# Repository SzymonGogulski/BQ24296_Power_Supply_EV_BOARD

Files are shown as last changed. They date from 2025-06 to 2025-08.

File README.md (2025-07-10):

# BQ24296 Power Supply 5V @ 3A

### Linki
* [Simple way to use USB-C 5V@3A](https://forum.digikey.com/t/simple-way-to-use-usb-type-c-to-get-5v-at-up-to-3a-15w/7016)

### Notatki
* BQ24296
    * Sprawdź default input current limit,
    * Sprawdź czy wyjście VSYS jest regulowane na 5.0V,
    * Sprawdź co to NVDC power path management,

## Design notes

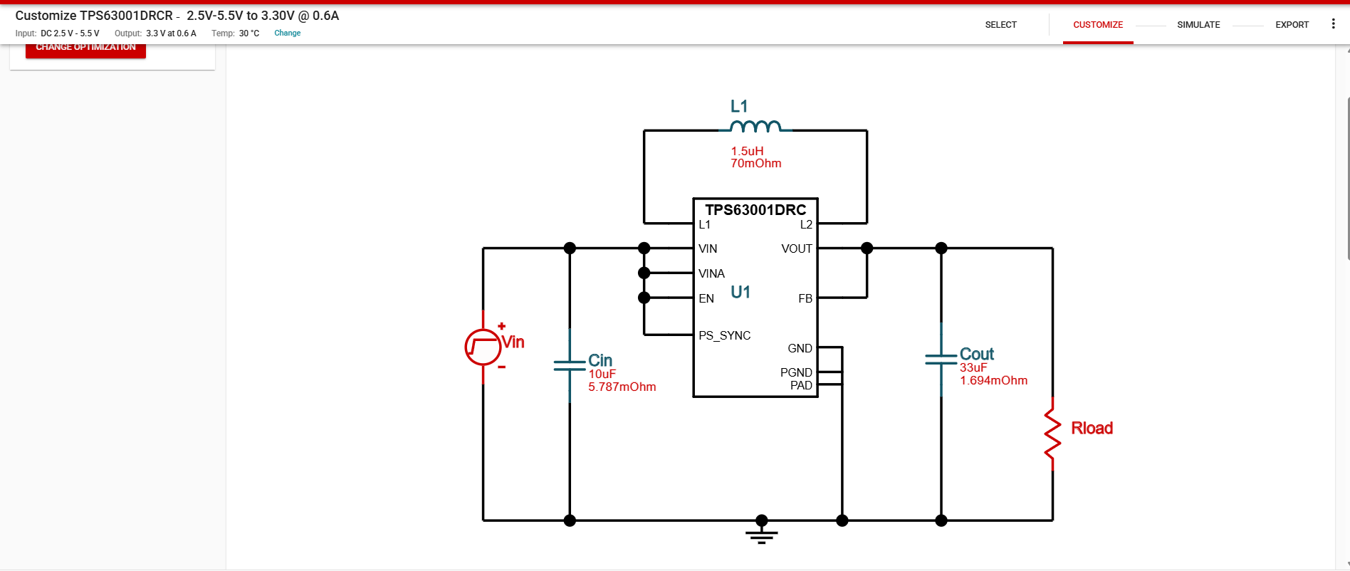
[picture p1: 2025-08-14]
Dokumentacja/3V3_24.06.2025.png

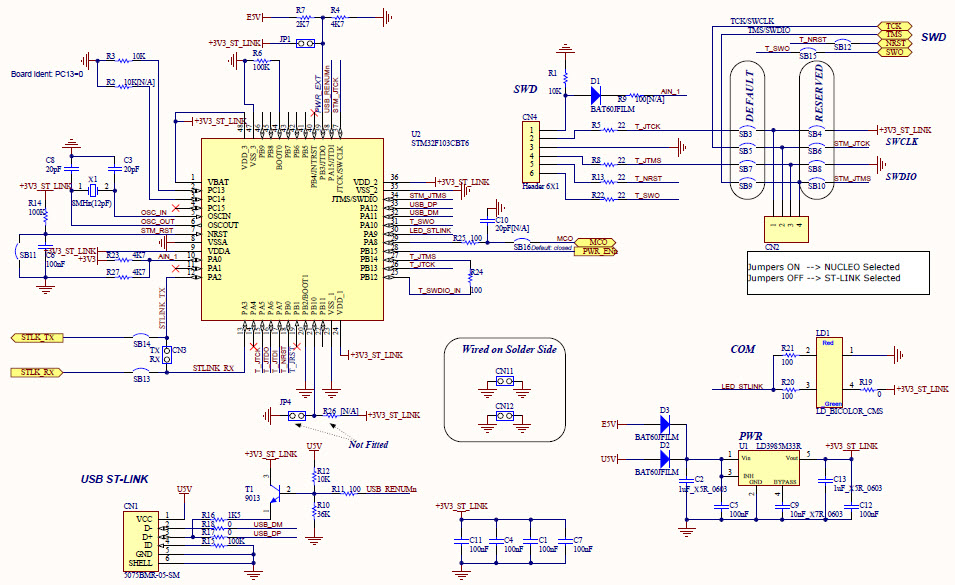
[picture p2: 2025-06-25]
Dokumentacja/stm32nucleo-64_fig.1_5.jpg

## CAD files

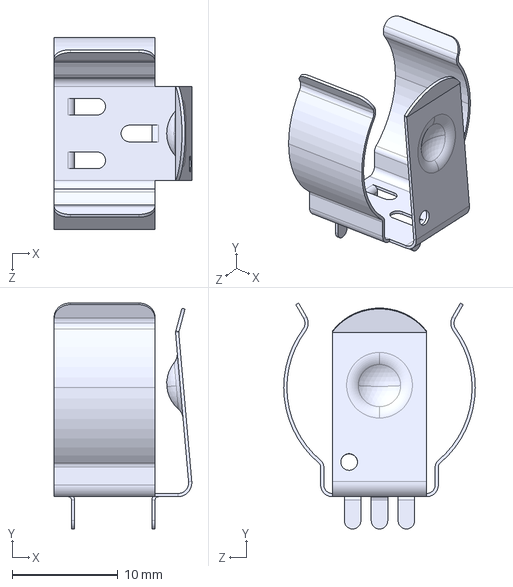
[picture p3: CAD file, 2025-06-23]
BQ2xxxx/Biblioteki/54/54.step
13.0 x 21.4 x 18.1 mm

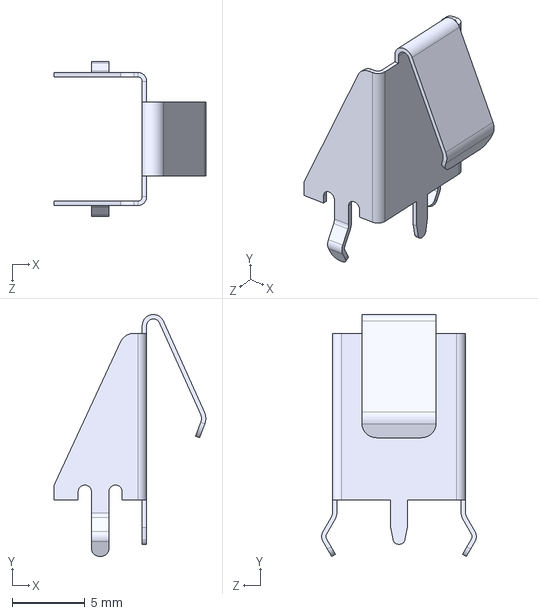
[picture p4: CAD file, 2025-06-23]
BQ2xxxx/Biblioteki/590/590.step
10.4 x 16.6 x 10.6 mm

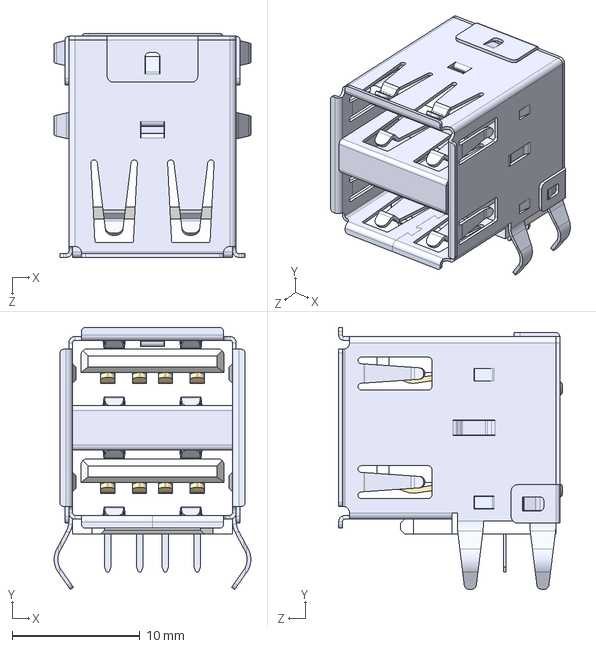
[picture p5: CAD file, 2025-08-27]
BQ2xxxx/Biblioteki/AU-Y1008-2/AU-Y1008-2.step
15.4 x 20.5 x 17.5 mm

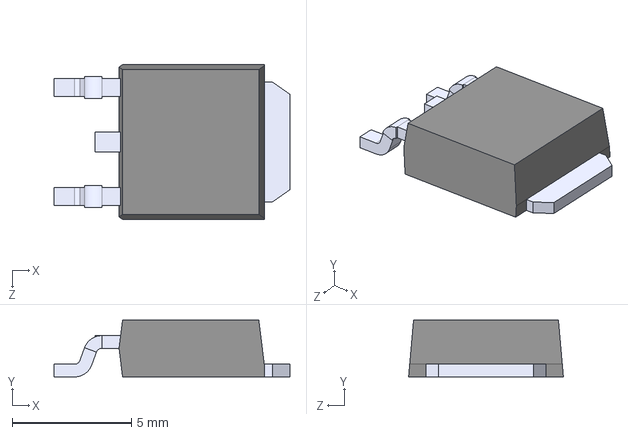
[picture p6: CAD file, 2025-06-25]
BQ2xxxx/Biblioteki/MJD31CG/MJD31CG.step
9.91 x 2.39 x 6.50 mm

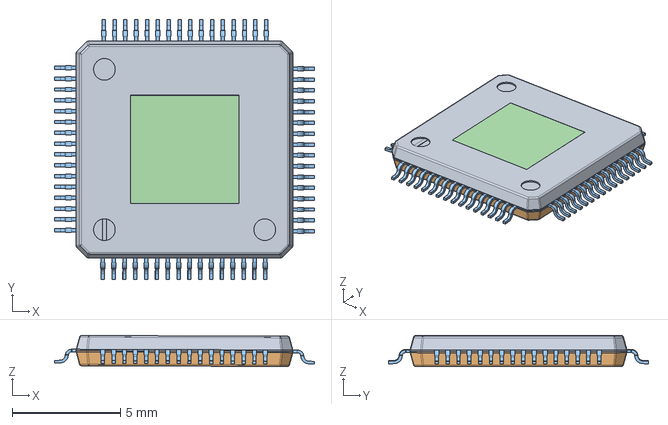
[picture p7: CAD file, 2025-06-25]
BQ2xxxx/Biblioteki/STM32F030R8T6/STM32F030R8T6.stp
12.0 x 12.0 x 1.43 mm

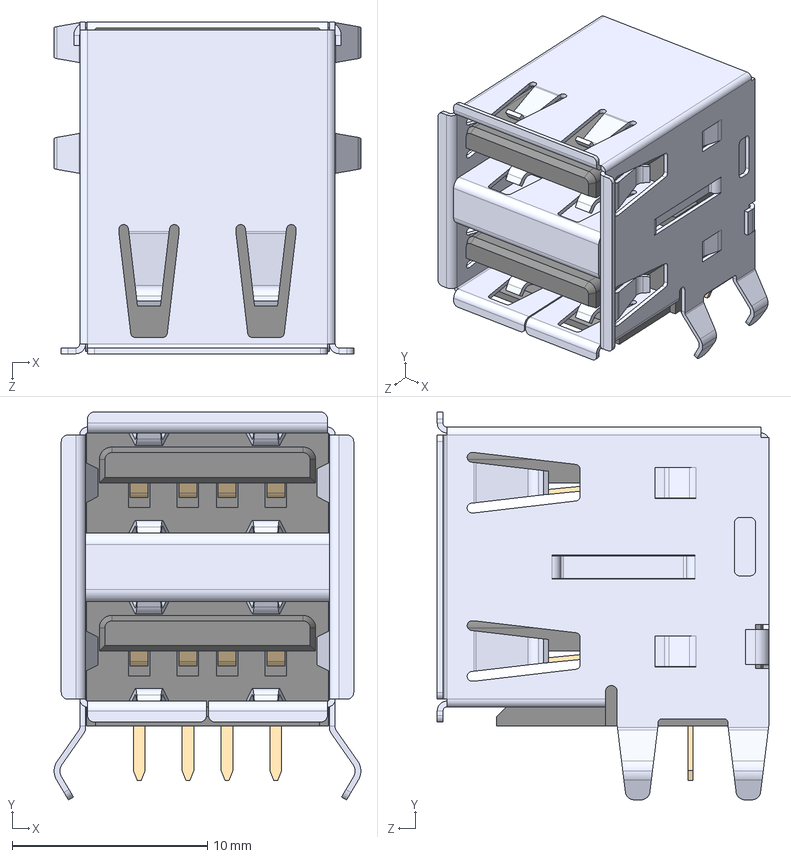
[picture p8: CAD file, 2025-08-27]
BQ2xxxx/Biblioteki/USB1035_GF_P_0_B_B/USB1035-XX-X-X-X-B_REVE.step
15.7 x 19.9 x 17.0 mm

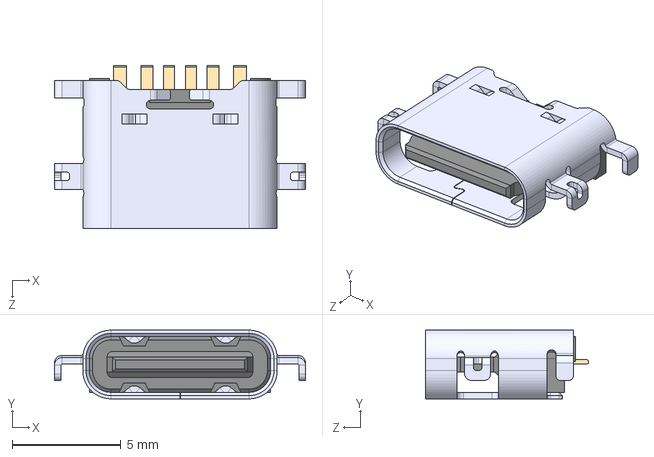
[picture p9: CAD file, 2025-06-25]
BQ2xxxx/Biblioteki/USB4515-GF-A_REVA/USB4515-GF-A_REVA.step
11.5 x 3.16 x 7.50 mm

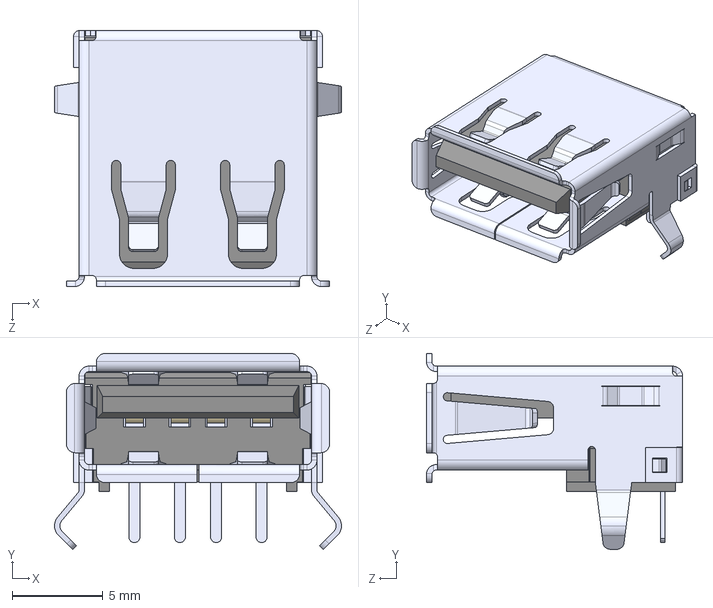
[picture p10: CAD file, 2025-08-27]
BQ2xxxx/Biblioteki/USB_A1HSW6/USB-A1HSW6.step
15.8 x 10.8 x 14.1 mm

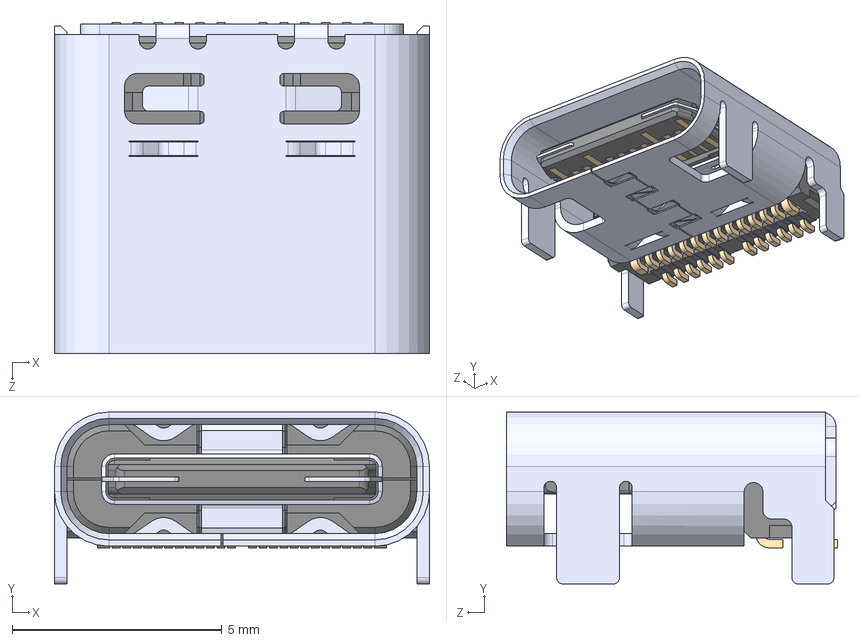
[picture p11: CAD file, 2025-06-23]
BQ2xxxx/Biblioteki/1054500101/1054500101--3DModel-STEP-1.STEP
8.94 x 4.10 x 7.90 mm

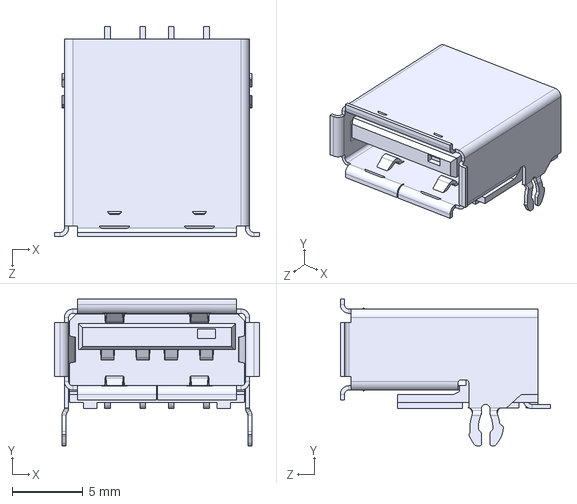
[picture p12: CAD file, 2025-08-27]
BQ2xxxx/Biblioteki/87583-0010RHLF/87583-0010RHLF.step
14.5 x 10.4 x 14.9 mm

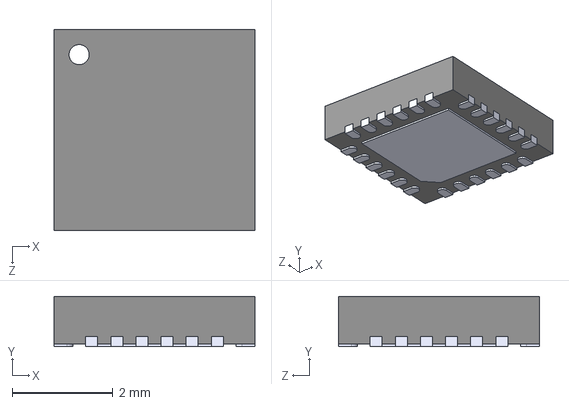
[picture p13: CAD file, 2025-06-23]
BQ2xxxx/Biblioteki/BQ24296MRGER/BQ24296MRGER.step
4.00 x 1.00 x 4.00 mm

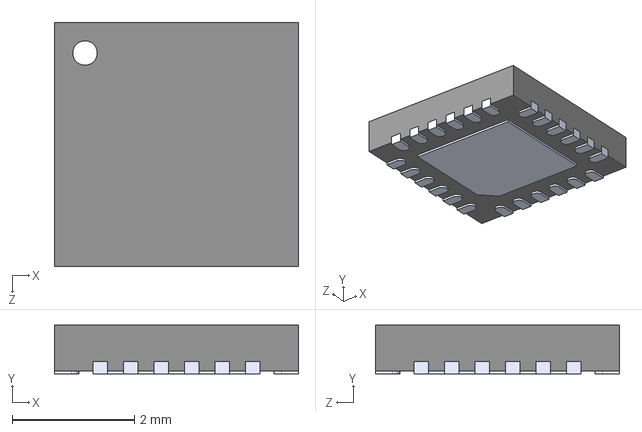
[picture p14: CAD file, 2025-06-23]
BQ2xxxx/Biblioteki/BQ25895MRTWT/BQ25895MRTWT.step
4.00 x 0.8 x 4.00 mm

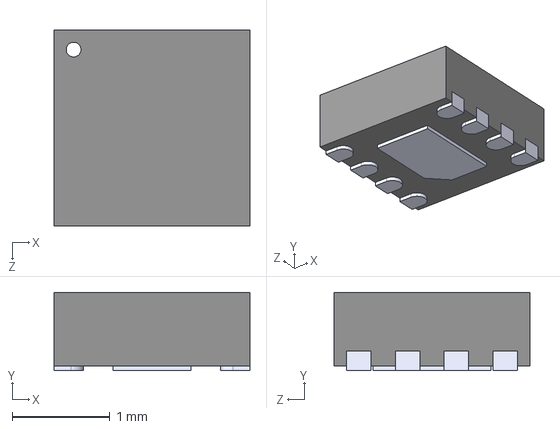
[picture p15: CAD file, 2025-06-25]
BQ2xxxx/Biblioteki/MAX17048G_T10/MAX17048G_T10.step
2.00 x 0.8 x 2.00 mm

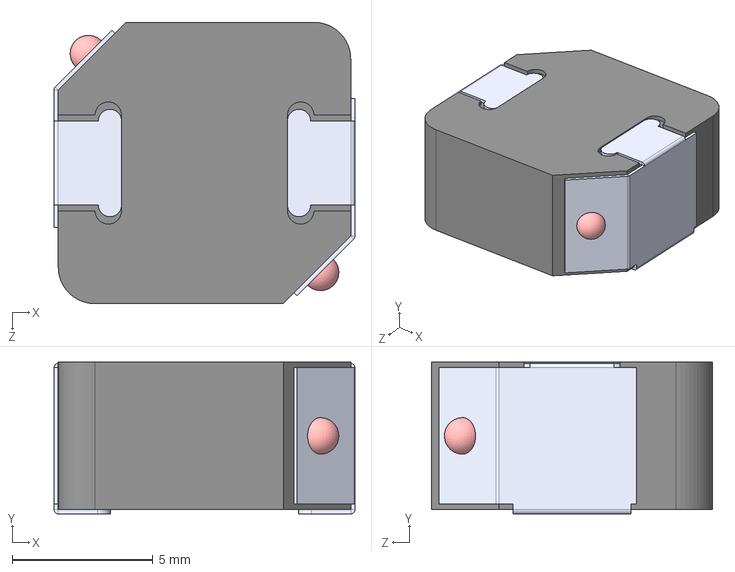
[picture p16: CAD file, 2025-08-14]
BQ2xxxx/Biblioteki/SPM10054T_1R5M_HZ/SPM10054T-1R5M-HZ.step
10.7 x 5.40 x 10.0 mm

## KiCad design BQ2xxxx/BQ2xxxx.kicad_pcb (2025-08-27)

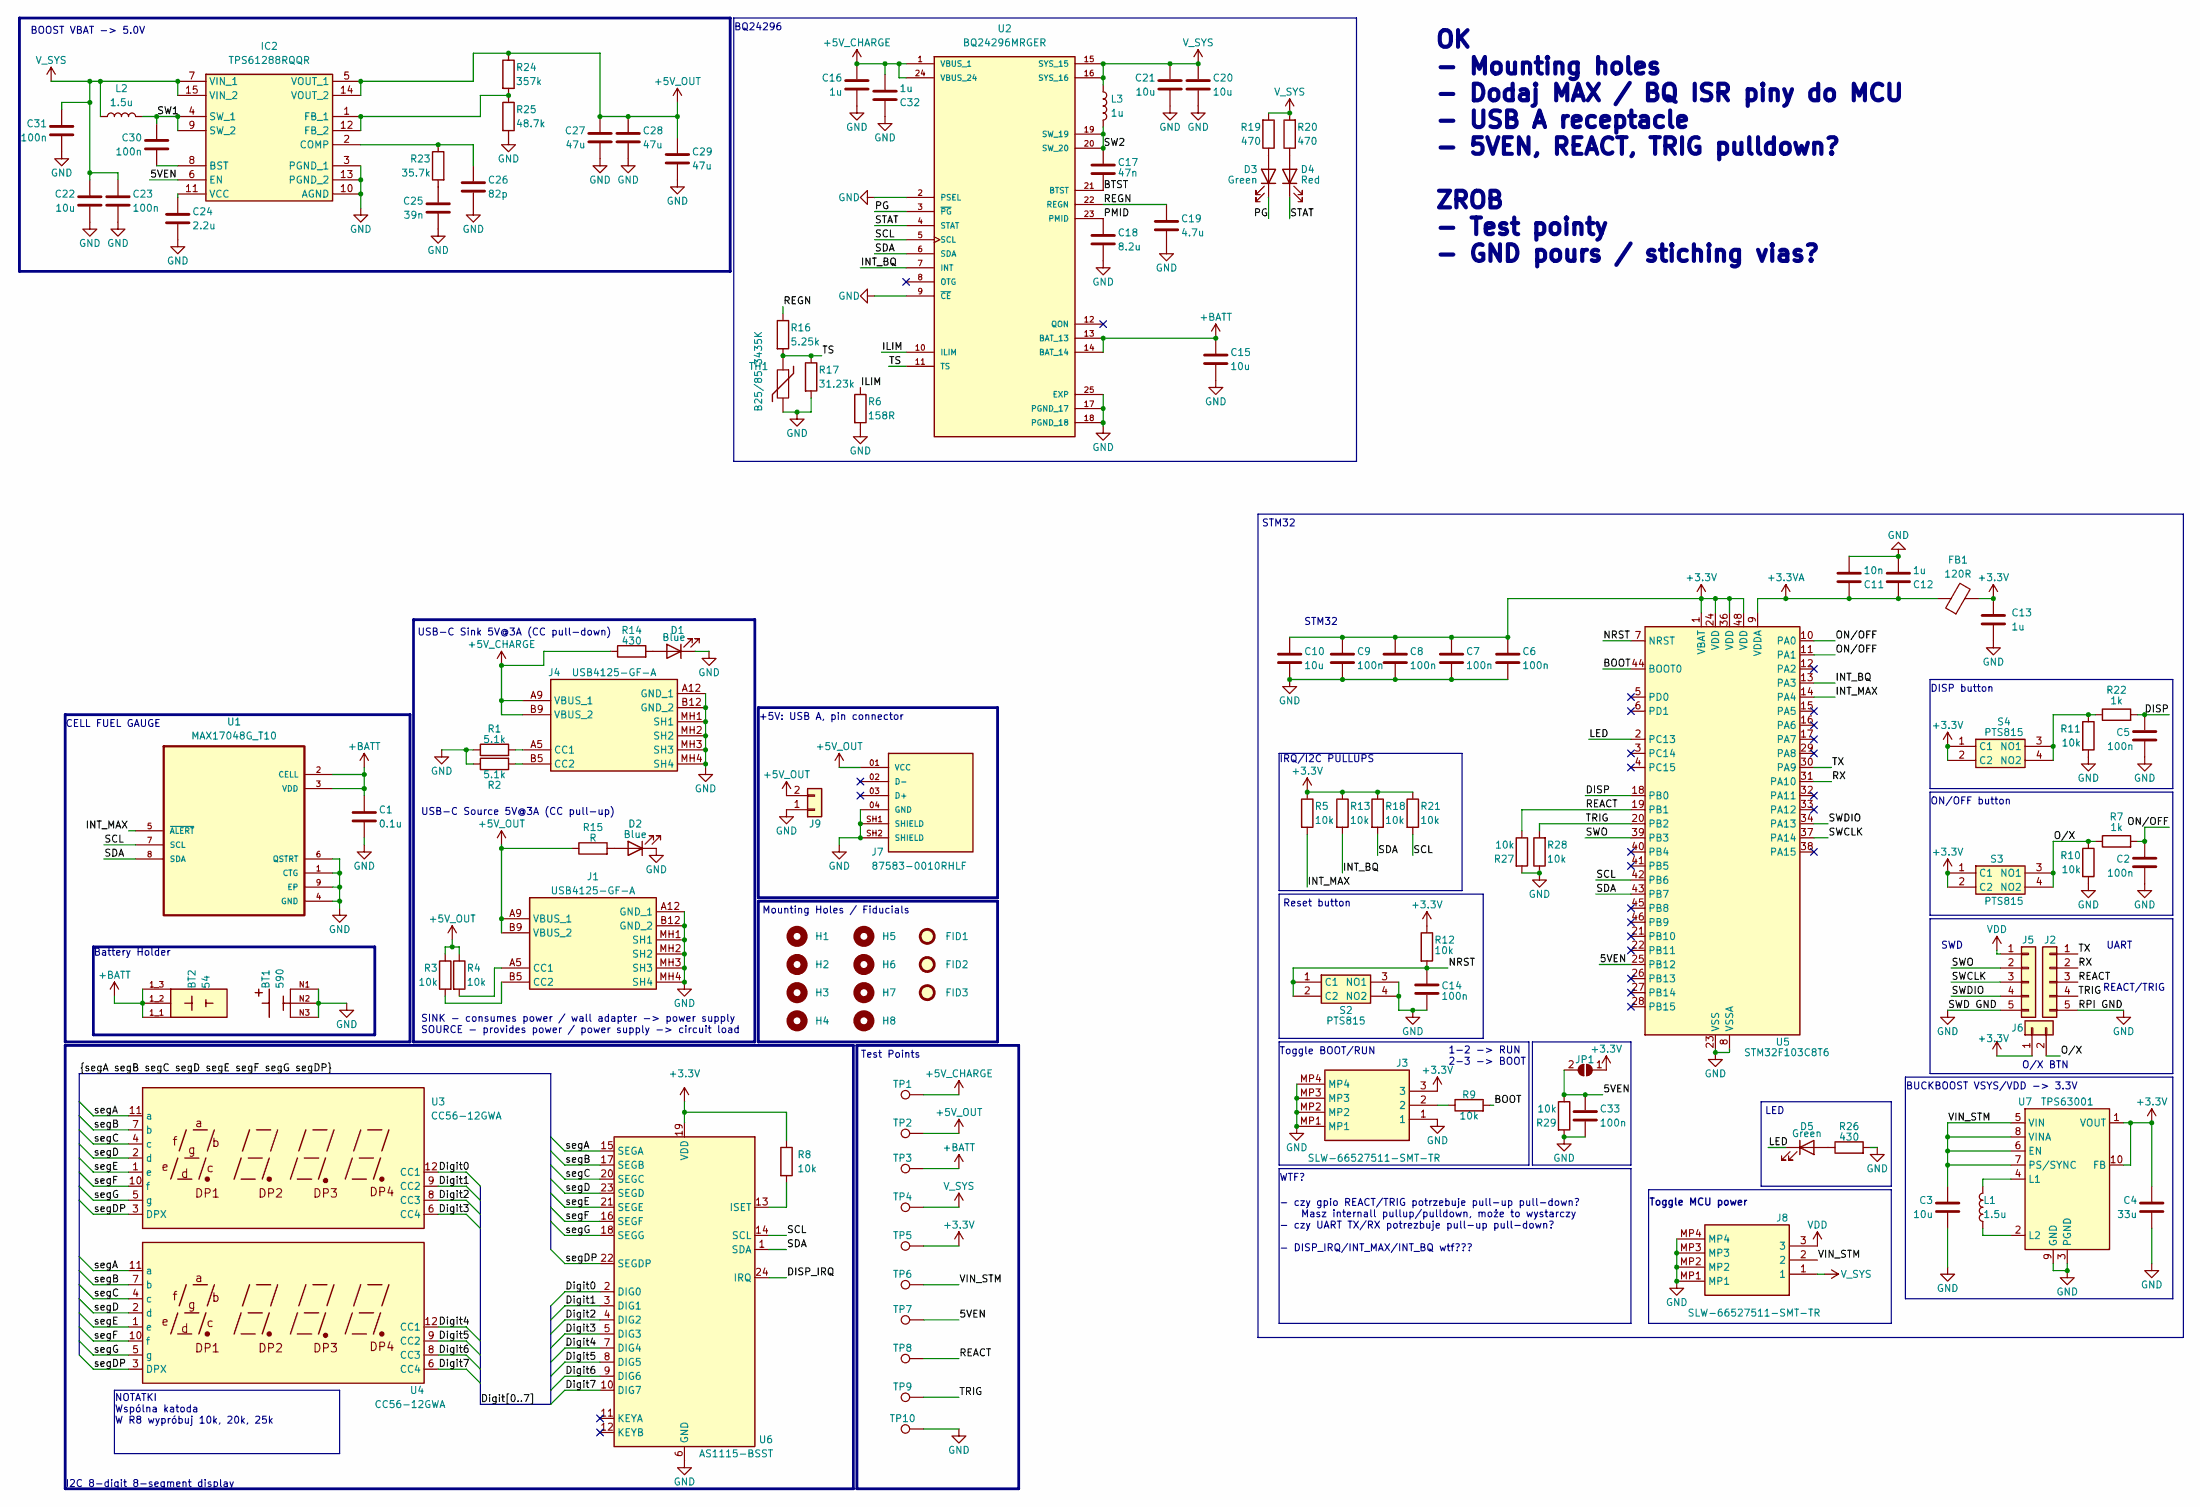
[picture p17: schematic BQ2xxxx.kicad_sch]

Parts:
BT1: 590; BAT_590; PARTREV E
BT2: 54; BAT_54; PARTREV E
C1: 0.1u; C_0402_1005Metric
C2, C5, C6, C7, C8, C9, C14, C23, C30, C31, C33: 100n; C_0402_1005Metric
C3, C10, C15, C20, C21: 10u; C_0603_1608Metric
C4: 33u; C_0805_2012Metric
C11: 10n; C_0402_1005Metric
C12, C13, C16, C32: 1u; C_0402_1005Metric
C17: 47n; C_0402_1005Metric
C18: 8.2u; C_0603_1608Metric
C19: 4.7u; C_0603_1608Metric
C22: 10u; C_0805_2012Metric
C24: 2.2u; C_0402_1005Metric
C25: 39n; C_0402_1005Metric
C26: 82p; C_0402_1005Metric
C27, C28, C29: 47u; C_0805_2012Metric
D1, D2: Blue; LED_0402_1005Metric
D3, D5: Green; LED_0402_1005Metric
D4: Red; LED_0402_1005Metric
FB1: 120R; R_0402_1005Metric
FID1, FID2, FID3: Fiducial; stencil_pin
H1, H2, H3, H4, H5, H6, H7, H8: MountingHole; MountingHole_2.2mm_M2
IC2: TPS61288RQQR; Mouser Part Number 595-TPS61288RQQR
J1, J4: USB4125-GF-A; USB4125GFA; Manufacturer_Part_Number USB4125-GF-A
J2, J5: Conn_01x05; PinSocket_1x05_P2.54mm_Vertical
J3, J8: SLW-66527511-SMT-TR; SLW66527511SMTTR; Mouser Part Number 179-SLW66527511SMTTR
J6, J9: Conn_01x02; PinHeader_1x02_P2.54mm_Vertical
J7: 87583-0010RHLF; AMPHENOL_87583-0010RHLF; PARTREV AD
JP1: SolderJumper_2_Open; R_0805_2012Metric
L1: 1.5u; L_1008_2520Metric
L2: 1.5u; L_6.3x6.3_H3
L3: 1u; IND_R2M01_VIS
R1, R2: 5.1k; R_0402_1005Metric
R3, R4, R5, R8, R9, R10, R11, R12, R13, R18, R21, R27, R28, R29: 10k; R_0402_1005Metric
R6: 158R; R_0402_1005Metric
R7, R22: 1k; R_0402_1005Metric
R14, R26: 430; R_0402_1005Metric
R15: R; R_0402_1005Metric
R16: 5.25k; R_0402_1005Metric
R17: 31.23k; R_0402_1005Metric
R19, R20: 470; R_0402_1005Metric
R23: 35.7k; R_0402_1005Metric
R24: 357k; R_0402_1005Metric
R25: 48.7k; R_0402_1005Metric
S2, S3, S4: PTS815; PTS815SJM250SMTRLFS; Mouser Part Number 611-PTS815SJM250SMTR
TH1: B25/85 3435K; R_0805_2012Metric
TP1, TP2, TP3, TP4, TP5, TP6, TP7, TP8, TP9: TestPoint; TestPoint_Pad_1.0x1.0mm
TP10: TestPoint; TestPoint_Pad_D3.0mm
U1: MAX17048G_T10; SON50P200X200X80-9N; DigiKey_Part_Number MAX17048G+T10TR-ND
U2: BQ24296MRGER; QFN50P400X400X100-25N; PARTREV 4219013/A 05/2017
U3, U4: CC56-12GWA
U5: STM32F103C8T6; LQFP-48_7x7mm_P0.5mm
U6: AS1115-BSST; QSOP-24_3.9x8.7mm_P0.635mm
U7: TPS63001; Texas_DRC0010J

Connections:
+3.3V: C4.1, C6.1, C7.1, C8.1, C9.1, C10.1, C13.1, FB1.2, J3.3, J6.1, JP1.1 (A), R5.1, R8.1, R12.1, R13.1, R18.1, R21.1, S3.1 (C1), S3.2 (C2), S4.1 (C1), S4.2 (C2), TP5.1, U5.1 (VBAT), U5.24 (VDD), U5.36 (VDD), U5.48 (VDD), U6.19 (VDD), U7.1 (VOUT), U7.10 (FB)
+3.3VA: C11.1, C12.1, FB1.1, U5.9 (VDDA)
+5V_CHARGE: C16.1, C32.2, J4.A9 (VBUS_1), J4.B9 (VBUS_2), R14.1, TP1.1, U2.1 (VBUS_1), U2.24 (VBUS_24)
+5V_OUT: C27.1, C28.1, C29.1, IC2.5 (VOUT_1), IC2.14 (VOUT_2), J1.A9 (VBUS_1), J1.B9 (VBUS_2), J7.01 (VCC), J9.2, R3.1, R4.1, R15.1, R24.1, TP2.1
+BATT: BT2.1_1, BT2.1_2, BT2.1_3, C1.1, C15.1, TP3.1, U1.2 (CELL), U1.3 (VDD), U2.13 (BAT_13), U2.14 (BAT_14)
/5VEN: C33.1, IC2.6 (EN), JP1.2 (B), R29.1, TP7.1, U5.25 (PB12)
/BOOT: R9.2, U5.44 (BOOT0)
/BTST: C17.2, U2.21 (BTST)
/DISP: C5.1, R22.2, U5.18 (PB0)
/DISP_IRQ: U6.24 (IRQ)
/Digit0: U3.12 (CC1), U6.2 (DIG0)
/Digit1: U3.9 (CC2), U6.3 (DIG1)
/Digit2: U3.8 (CC3), U6.4 (DIG2)
/Digit3: U3.6 (CC4), U6.5 (DIG3)
/Digit4: U4.12 (CC1), U6.7 (DIG4)
/Digit5: U4.9 (CC2), U6.8 (DIG5)
/Digit6: U4.8 (CC3), U6.9 (DIG6)
/Digit7: U4.6 (CC4), U6.10 (DIG7)
/ILIM: R6.1, U2.10 (ILIM)
/INT_BQ: R13.2, U2.7 (INT), U5.13 (PA3)
/INT_MAX: R5.2, U1.5 (~ALERT), U5.14 (PA4)
/LED: D5.1 (K), U5.2 (PC13)
/NRST: C14.1, R12.2, S2.1 (C1), S2.2 (C2), U5.7 (NRST)
/ON/OFF: C2.1, R7.2, U5.10 (PA0), U5.11 (PA1)
/O/X: J6.2, R7.1, R10.1, S3.3 (NO1), S3.4 (NO2)
/PG: D3.1 (K), U2.3 (~PG)
/PMID: C18.1, U2.23 (PMID)
/REACT: J2.3, R27.1, TP8.1, U5.19 (PB1)
/REGN: C19.1, R16.1, U2.22 (REGN)
/RX: J2.2, U5.31 (PA10)
/SCL: R21.2, U1.7 (SCL), U2.5 (SCL), U5.42 (PB6), U6.14 (SCL)
/SDA: R18.2, U1.8 (SDA), U2.6 (SDA), U5.43 (PB7), U6.1 (SDA)
/STAT: D4.1 (K), U2.4 (STAT)
/SW1: C30.2, IC2.4 (SW_1), IC2.9 (SW_2), L2.1
/SW2: C17.1, L3.2, U2.19 (SW_19), U2.20 (SW_20)
/SWCLK: J5.3, U5.37 (PA14)
/SWDIO: J5.4, U5.34 (PA13)
/SWO: J5.2, U5.39 (PB3)
/TRIG: J2.4, R28.2, TP9.1, U5.20 (PB2)
/TS: R16.2, R17.1, TH1.1, U2.11 (TS)
/TX: J2.1, U5.30 (PA9)
/VIN_STM: C3.1, J8.2, TP6.1, U7.5 (VIN), U7.6 (EN), U7.7 (PS/SYNC), U7.8 (VINA)
/segA: U3.11 (a), U4.11 (a), U6.15 (SEGA)
/segB: U3.7 (b), U4.7 (b), U6.17 (SEGB)
/segC: U3.4 (c), U4.4 (c), U6.20 (SEGC)
/segD: U3.2 (d), U4.2 (d), U6.23 (SEGD)
/segDP: U3.3 (DPX), U4.3 (DPX), U6.22 (SEGDP)
/segE: U3.1 (e), U4.1 (e), U6.21 (SEGE)
/segF: U3.10 (f), U4.10 (f), U6.16 (SEGF)
/segG: U3.5 (g), U4.5 (g), U6.18 (SEGG)
GND: BT1.N1, BT1.N2, BT1.N3, C1.2, C2.2, C3.2, C4.2, C5.2, C6.2, C7.2, C8.2, C9.2, C10.2, C11.2, C12.2, C13.2, C14.2, C15.2, C16.2, C18.2, C19.2, C20.2, C21.2, C22.1, C23.2, C24.2, C25.2, C26.2, C27.2, C28.2, C29.2, C31.2, C32.1, C33.2, D1.1 (K), D2.1 (K), IC2.3 (PGND_1), IC2.10 (AGND), IC2.13 (PGND_2), J1.A12 (GND_1), J1.B12 (GND_2), J1.MH1 (SH1), J1.MH2 (SH2), J1.MH3 (SH3), J1.MH4 (SH4), J2.5, J3.1, J3.MP1, J3.MP2, J3.MP3, J3.MP4, J4.A12 (GND_1), J4.B12 (GND_2), J4.MH1 (SH1), J4.MH2 (SH2), J4.MH3 (SH3), J4.MH4 (SH4), J5.5, J7.04 (GND), J7.SH1 (SHIELD), J7.SH2 (SHIELD), J8.MP1, J8.MP2, J8.MP3, J8.MP4, J9.1, R1.1, R2.1, R6.2, R10.2, R11.2, R17.2, R25.2, R26.2, R27.2, R28.1, R29.2, S2.3 (NO1), S2.4 (NO2), TH1.2, TP10.1, U1.1 (CTG), U1.4 (GND), U1.6 (QSTRT), U1.9 (EP), U2.2 (PSEL), U2.9 (~CE), U2.17 (PGND_17), U2.18 (PGND_18), U2.25 (EXP), U5.8 (VSSA), U5.23 (VSS), U5.35 (VSS), U5.47 (VSS), U6.6 (GND), U7.3 (PGND), U7.9 (GND), U7.11 (PGND)
unnamed: C25.1, R23.2
unnamed: D1.2 (A), R14.2
unnamed: D2.2 (A), R15.2
unnamed: D3.2 (A), R19.1
unnamed: D4.2 (A), R20.1
unnamed: D5.2 (A), R26.1
unnamed: C30.1, IC2.8 (BST)
unnamed: C26.1, IC2.2 (COMP), R23.1
unnamed: IC2.1 (FB_1), IC2.12 (FB_2), R24.2, R25.1
unnamed: C24.1, IC2.11 (VCC)
unnamed: J1.A5 (CC1), R4.2
unnamed: J1.B5 (CC2), R3.2
unnamed: J3.2, R9.1
unnamed: J4.A5 (CC1), R1.2
unnamed: J4.B5 (CC2), R2.2
unnamed: R11.1, R22.1, S4.3 (NO1), S4.4 (NO2)
unnamed: R8.2, U6.13 (ISET)
unnamed: L1.2, U7.4 (L1)
unnamed: L1.1, U7.2 (L2)
VDD: J5.1, J8.3
V_SYS: C20.1, C21.1, C22.2, C23.1, C31.1, IC2.7 (VIN_1), IC2.15 (VIN_2), J8.1, L2.2, L3.1, R19.2, R20.2, TP4.1, U2.15 (SYS_15), U2.16 (SYS_16)

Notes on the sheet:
Reset button
USB-C Source 5V@3A (CC pull-up)
Battery Holder
Mounting Holes / Fiducials
BUCKBOOST VSYS/VDD -> 3.3V
ON/OFF button
IRQ/I2C PULLUPS
DISP button
UART
STM32
LED
O/X BTN
WTF?
REACT/TRIG
SINK - consumes power / wall adapter -> power supply SOURCE - provides power / power supply -> circuit load
USB-C Sink 5V@3A (CC pull-down)
Toggle BOOT/RUN
Test Points
- czy gpio REACT/TRIG potrzebuje pull-up pull-down? Masz internall pullup/pulldown, może to wystarczy - czy UART TX/RX potrezbuje pull-up pull-down? - DISP_IRQ/INT_MAX/INT_BQ wtf???
1-2 -> RUN 2-3 -> BOOT
NOTATKI Wspólna katoda W R8 wypróbuj 10k, 20k, 25k
CELL FUEL GAUGE
BQ24296
SWD
BOOST VBAT -> 5.0V
+5V: USB A, pin connector
I2C 8-digit 8-segment display
OK - Mounting holes - Dodaj MAX / BQ ISR piny do MCU - USB A receptacle - 5VEN, REACT, TRIG pulldown? ZROB - Test pointy - GND pours / stiching vias?
Toggle MCU power

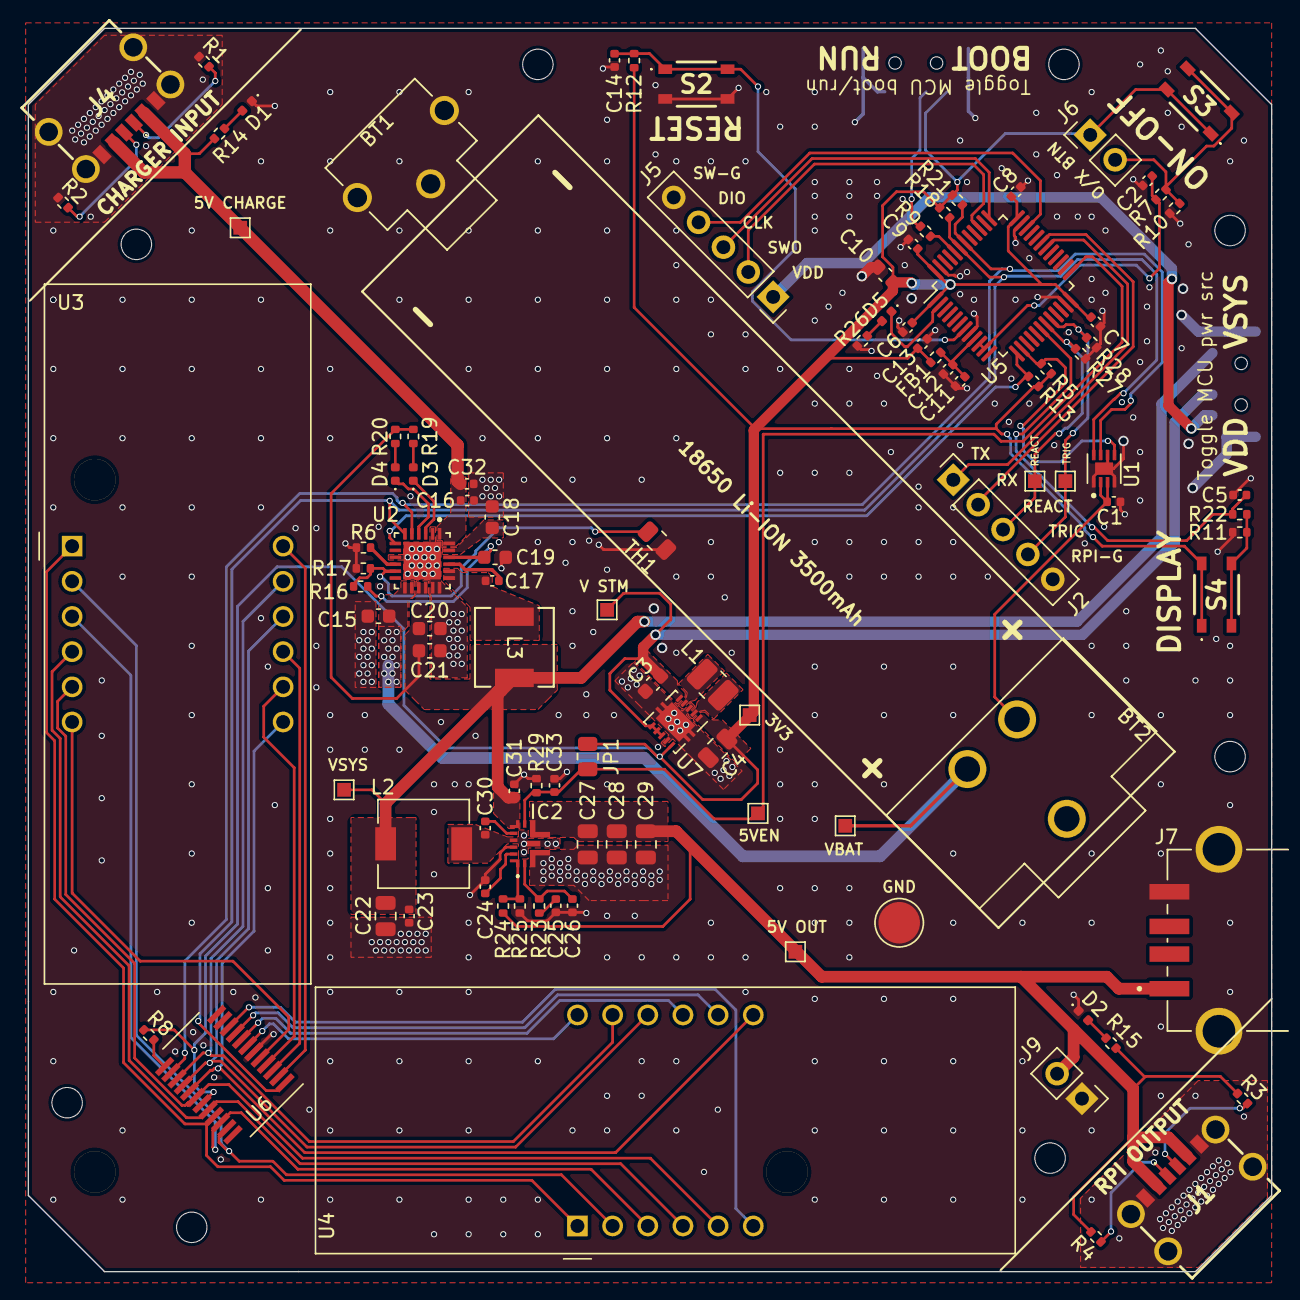
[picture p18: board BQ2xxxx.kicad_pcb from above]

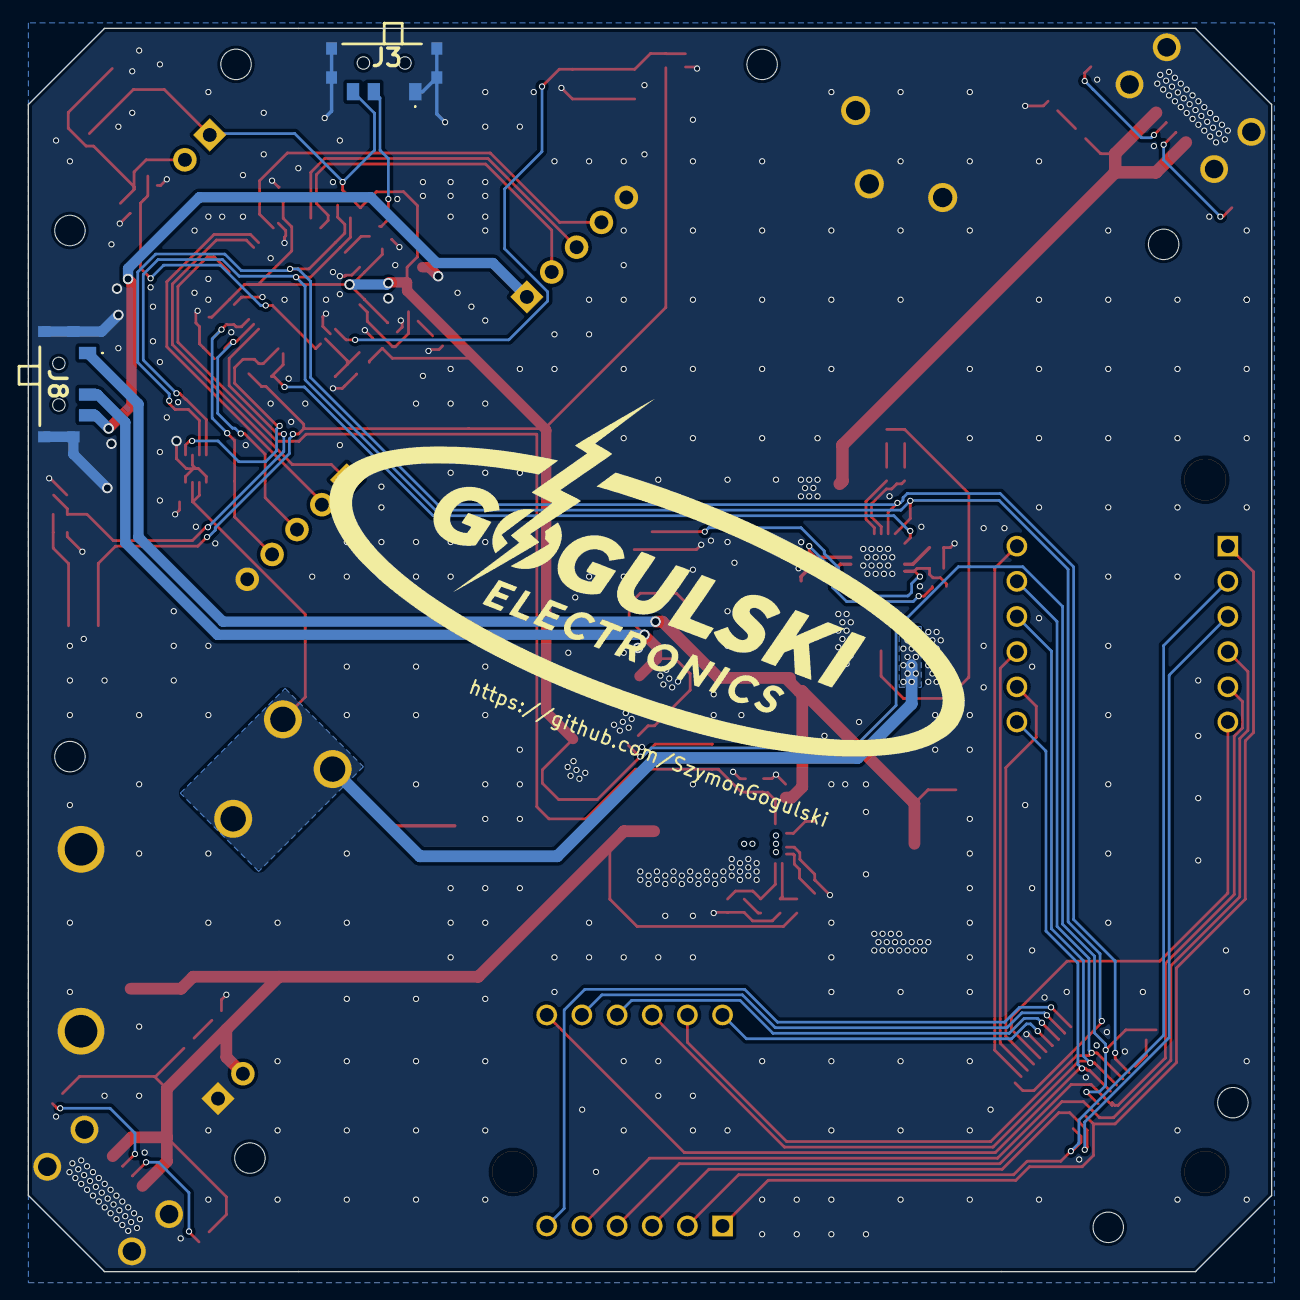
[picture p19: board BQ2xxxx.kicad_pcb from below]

Board: 4 copper layers, 89.8 x 89.8 mm, 116 parts (2 on the bottom side), 71 nets.

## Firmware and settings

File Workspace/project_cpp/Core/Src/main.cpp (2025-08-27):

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
/* Includes ------------------------------------------------------------------*/
#include "main.h"

/* USER CODE BEGIN Includes */
#include "FSM.h"
#include <stdbool.h>
#include <stdio.h>
#include <stdint.h>
//#include "core_cm4.h"  // or core_cm3.h, depending on your STM32

extern "C" int _write(int file, char *ptr, int len) {
    for (int i = 0; i < len; i++) {
        ITM_SendChar(*ptr++);
    }
    return len;
}
/* USER CODE END Includes */

I2C_HandleTypeDef hi2c1;

UART_HandleTypeDef huart1;

void SystemClock_Config(void);
static void MX_GPIO_Init(void);
static void MX_I2C1_Init(void);
static void MX_USART1_UART_Init(void);
/**
  * @brief  The application entry point.
  * @retval int
  */
int main(void)
{

  /* MCU Configuration--------------------------------------------------------*/

  /* Reset of all peripherals, Initializes the Flash interface and the Systick. */
  HAL_Init();

  /* Configure the system clock */
  SystemClock_Config();

  /* Initialize all configured peripherals */
  MX_GPIO_Init();
  MX_I2C1_Init();
  MX_USART1_UART_Init();
  /* USER CODE BEGIN 2 */
  //user_code_2();
  /* USER CODE END 2 */

  /* Infinite loop */
  /* USER CODE BEGIN WHILE */
  while (1)
  {
    /* USER CODE END WHILE */

	  /* USER CODE BEGIN 3 */
	  HAL_GPIO_WritePin(GPIOB, GPIO_PIN_9, GPIO_PIN_RESET);
	  HAL_Delay(1000);
	  HAL_GPIO_WritePin(GPIOB, GPIO_PIN_9, GPIO_PIN_SET);
	  HAL_Delay(1000);
	  //user_code_3();
  }
  /* USER CODE END 3 */
}

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


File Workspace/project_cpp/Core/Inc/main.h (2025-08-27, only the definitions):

#define LED_Pin GPIO_PIN_13
#define LED_GPIO_Port GPIOC
#define ON_Pin GPIO_PIN_0
#define ON_GPIO_Port GPIOA
#define OFF_Pin GPIO_PIN_1
#define OFF_GPIO_Port GPIOA
#define INT_BQ_Pin GPIO_PIN_3
#define INT_BQ_GPIO_Port GPIOA
#define INT_MAX_Pin GPIO_PIN_4
#define INT_MAX_GPIO_Port GPIOA
#define DISP_Pin GPIO_PIN_0
#define DISP_GPIO_Port GPIOB
#define REACT_Pin GPIO_PIN_1
#define REACT_GPIO_Port GPIOB
#define TRIG_Pin GPIO_PIN_2
#define TRIG_GPIO_Port GPIOB
#define EN5V_Pin GPIO_PIN_12
#define EN5V_GPIO_Port GPIOB

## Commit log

2025-06-25 MAIN: 25.06.2025
    [BQ2xxxx-B_Cu.gbr, BQ2xxxx-B_Mask.gbr, BQ2xxxx-B_Paste.gbr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]
2025-07-10 Work in progress: Schematic
    [BQ2xxxx.kicad_pcb, BQ2xxxx.kicad_sch]
2025-08-14 14.08 save
    [BQ2xxxx.kicad_pcb, BQ2xxxx.kicad_sch, SPM10054T-1R5M-HZ.step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]
2025-08-27 PCB wersja 1.0 koniec
    [87583-0010RHLF.step, AU-Y1008-2.step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]

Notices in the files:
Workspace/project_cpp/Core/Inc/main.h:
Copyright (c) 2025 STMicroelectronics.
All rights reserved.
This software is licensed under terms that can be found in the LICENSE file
